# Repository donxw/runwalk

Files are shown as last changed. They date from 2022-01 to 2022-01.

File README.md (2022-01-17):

# runwalk timer
Timer to help in trainging for marathons.  Set run vs walk time.  Ratio of run to walk is set by web page hosted by the ESP32.

## parts ##

1.  Heltec WifiKit32 with built in OLED screen
2.  400 mAh lipo battery
3.  Switch
4.  Piezo Buzzer

## wiring ##
runwalk_wiring

## operation ##
Power on device.  No default is set so on first boot follow these steps:
* connect to wireless AP broadcast by the ESP32:  SSID: runwalk / Password: 12345678
* navigate to webpage 192.168.10.2
* fill in the desired run and walk cycle times
* runwalk_webpage
* click submit - on submit the ESP32 will store the settings in EEPROM for future default settings
* disconnect from the wireless AP

Screen will show how much time you have run or walked, total cumulative run/walk time, icon to show current walk or run cycle and a bar chart to show how much time is left in the current cycle.
fullview (Small)

Piezo speaker will create a low-high tone when it is time to switch to running, 
run (Small)

and a high-low tone when it is time to walk.
walk (Small)

## case ##
A 3D printed case and plastic lens encase the electonics, buzzer and battery for use when running:
InCase (Small)

A switch and charging / programming port are on one side.  Note that the switch needs to be in the on position when charging the battery.

Connector (Small)

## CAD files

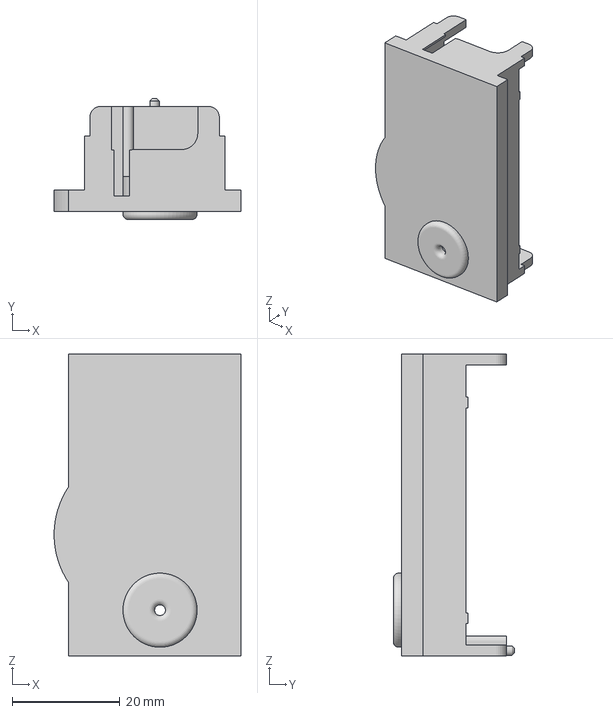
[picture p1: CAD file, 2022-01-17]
WalkRunTimer32v1/LowerCase^WalkRunAssembly.3mf
34.6 x 22.5 x 56.0 mm

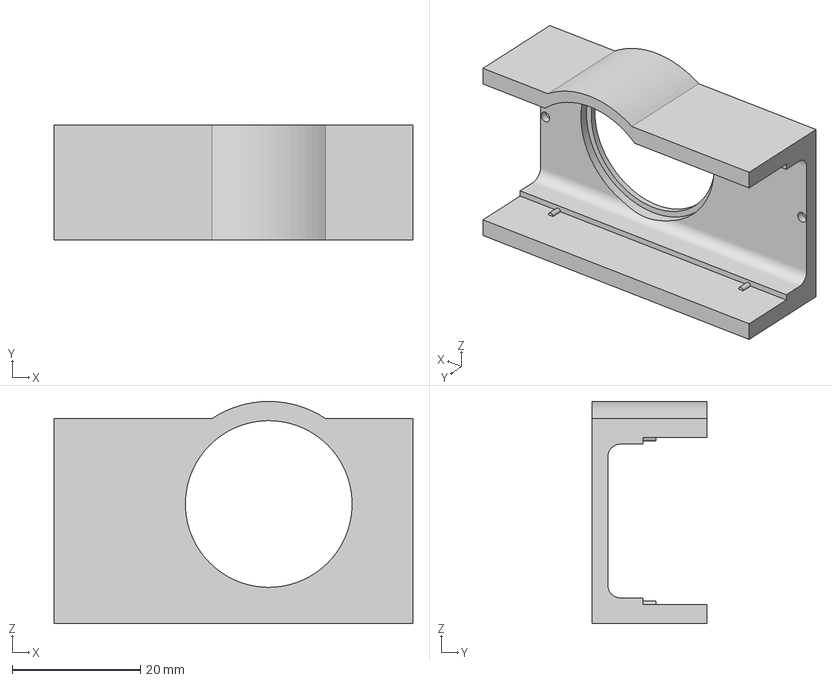
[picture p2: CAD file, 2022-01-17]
WalkRunTimer32v1/UpperCase.3mf
56.0 x 18.0 x 34.6 mm

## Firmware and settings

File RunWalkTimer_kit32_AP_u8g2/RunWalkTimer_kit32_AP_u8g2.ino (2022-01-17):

//Board:  Heltec Wifi Kit32
//https://www.w3schools.com/bootstrap/ to create index.h

#include <SPI.h>
#include <Wire.h>
#include <Adafruit_GFX.h>
#include <Adafruit_SSD1306.h>
#include <U8g2_for_Adafruit_GFX.h>
#include <Tone32.h>  //https://github.com/lbernstone/Tone
#include "UserSettings.h"

// WiFi and AP
#include <WiFi.h>
#include <WiFiClient.h>
#include <WebServer.h>
#include <DNSServer.h>
#include <EEPROM.h>
#include "index.h"

// Display Settings
#define SCREEN_WIDTH 128 // OLED display width, in pixels  128
#define SCREEN_HEIGHT 64 // OLED display height, in pixels  64
#define OLED_RESET     16 // For built in OLED wifikit8
Adafruit_SSD1306 display(SCREEN_WIDTH, SCREEN_HEIGHT, &Wire, OLED_RESET);
U8G2_FOR_ADAFRUIT_GFX u8display;

//  EEPROM configuration - 24 bytes
#define EEPROM_SIZE 24  /* new */

//  Settings for AP
const byte DNS_PORT = 53;
IPAddress apIP(192, 168, 10, 2); // hard code AP IP address (optional - default is 192.168.4.1)
DNSServer dnsServer;
WebServer server(80); //Server on port 80

// Intitialize variables
unsigned long previousTime = 0; // store the last time the led variable was updated
int led = 0;  //used as a counting variable and doubles as the number of LEDs to be lit
double cum_led = 0;  //cumulative count
bool walktime = true;
bool useEEPROMvalues = false;
bool useEEPROMnextboot = false;
bool toneOn = true;
int x_offset = 12;  //offset for led

// 600000 = 10 minutes in milliseconds (10 * 60 * 1000)
// 60000 = 1 minute in milliseconds
// 6000 = 6 sec in milliseconds
long interval = 10000; // 10sec interval - increments LED count
long setupInterval = 10000; // interval before moving out of setup automatically
int selectmode = 0;  // variable to store display function mode

//===============================================================
// This routine is executed when you open its IP in browser
//===============================================================
void handleRoot() {
  String s = MAIN_page; //Read HTML contents
  server.send(200, "text/html", s); //Send web page
}
//===============================================================
// This routine is executed when you press submit
//===============================================================
void handleForm() {
  String run__duration = server.arg("runTime");
  String walk__duration = server.arg("walkTime");
  String tone__on = server.arg("tone");

  // this is a cool way to convert string from the web page to an integer
  run_duration = atoi(run__duration.c_str());
  walk_duration = atoi(walk__duration.c_str());

  run_duration = run_duration * 1000 / interval;
  walk_duration = walk_duration * 1000 / interval;

  Serial.print("Run Duration:");
  Serial.println(run_duration);

  Serial.print("Walk Duration:");
  Serial.println(walk_duration);

  toneOn = (tone__on == "on") ? true : false;
  Serial.print("Tone is:  "); Serial.println(toneOn);

  selectmode = 1;  //set to one to start the run / walk cycle
  Serial.print("Selectmode = "); Serial.println(selectmode);

  led = 0; //set led count back to zero on new settings
  cum_led = 0;  //reset cumulative time back to zero

  useEEPROMnextboot = 1;  //flag to read from eeprom

  //Update web page with input values
  server.send(200, "text/html", run__duration + " " + walk__duration); //Send web page

  //Write values to EEPROM for next boot
  EEPROM.write(0, run_duration);
  EEPROM.write(1, walk_duration);
  EEPROM.write(2, useEEPROMnextboot);
  EEPROM.commit();


  // reset first display
  display.clearDisplay();
  u8display.setCursor(x_offset, 10);
  u8display.print("Walking: ");
  u8display.print(led * 10);
  u8display.println(" sec");
  display.drawBitmap(
    ((display.width() - 32 ) / 2) + 45,
    ((display.height() - 32) / 2) + 10,
    myWalker, 32, 32, 1);
  u8display.setCursor(x_offset, 25);
  u8display.print("Total: ");
  u8display.print(cum_led * interval / (60 * 1000));  u8display.println(" min");
  display.fillRect(0, 60, (10 * (walk_duration - led) * 127) / (10 * walk_duration), 4, WHITE);
  display.display();
}


void setup() {
  unsigned long currentTime = millis();

  // Set up EEPROM storage
  //===============================================================
  EEPROM.begin(EEPROM_SIZE);

  // initialize display
  Wire.begin(4, 15);
  // SSD1306_SWITCHCAPVCC = generate display voltage from 3.3V internally
  if (!display.begin(SSD1306_SWITCHCAPVCC, 0x3C)) { // Address 0x3C for 128x32
    Serial.println(F("SSD1306 allocation failed"));
    for (;;); // Don't proceed, loop forever
  }
  u8display.begin(display);  //connect u8g2 to adafruit gfx
  u8display.setFont(u8g2_font_ordinarybasis_tr); //u8g2_font_ordinarybasis_t_all
  //u8display.setFont(u8g2_font_seraphimb1_tr);
  //u8display.setFont(u8g2_font_koleeko_tf);
  //u8display.setFont(u8g2_font_DigitalDiscoThin_te);
  u8display.setFontMode(1);
  u8display.setFontDirection(0);
  u8display.setForegroundColor(WHITE);
  u8display.setCursor(0, 10);
  display.setRotation(0);  //0 is normal, 1 is 90, 2 is 180 and 3 is 270deg

  Serial.begin(115200);

  //Settings for webserver
  WiFi.mode(WIFI_AP); //Access Point mode
  WiFi.softAP("runwalk", "12345678");    //Password length minimum 8 char
  //WiFi.softAPConfig(local_ip, gateway, subnet);  //Optional - only if you don't want the default
  WiFi.softAPConfig(apIP, apIP, IPAddress(255, 255, 255, 0));
  dnsServer.setTTL(300); // modify TTL with the domain name from 60 to 300seconds
  dnsServer.setErrorReplyCode(DNSReplyCode::ServerFailure);
  dnsServer.start(DNS_PORT, "www.walkrun.com", apIP);  // set website name

  //Map server actions to functions
  server.on("/", handleRoot);      //Which routine to handle at root location
  server.on("/action_page", handleForm); //form action is handled here
  server.begin();                  //Start server
  Serial.println("HTTP server started");
  display.clearDisplay();
  u8display.setCursor(x_offset, 30);
  u8display.println("Connect Wifi to");
  u8display.setCursor(x_offset, 45);
  u8display.print("runwalk");
  display.display();
  display.setCursor(0, 10);

  delay(3000);  // delay to allow connection

  display.clearDisplay();
  u8display.setCursor(x_offset, 30);
  u8display.print("go to: ");
  u8display.print("192.168.10.2");
  display.display();

delay(1000);  //delay to read

  // convert walk_duration to number of loop cycles based on interval
  walk_duration = walk_duration * 1000 / interval; // convert to ms then divide by interval which is also in ms
  run_duration = run_duration * 1000 / interval;
  Serial.print("walk_duration:  ");  Serial.println(walk_duration);

  //Read values from eeprom if flag is set
  useEEPROMnextboot = EEPROM.read(2);
  // test to see if values were stored in EEPROM and load them
  Serial.print("useEEPROMnextboot from EEPROM: "); Serial.println(useEEPROMnextboot);
  if (useEEPROMnextboot = 1) {
    run_duration = EEPROM.read(0);
    walk_duration = EEPROM.read(1);
    Serial.println("*****From EEPROM**********");
    Serial.print("walk_duration: "); Serial.println(walk_duration);
    Serial.print("run_duration: "); Serial.println(run_duration);
  }

  Serial.println("Setup Complete");
  Serial.print("Selectmode = "); Serial.println(selectmode);

}

void loop() {

  // store the time since the Arduino started running in a variable
  unsigned long currentTime = millis();

  switch (selectmode) {

    case 0:  // walking

      server.handleClient();          //Handle client requests


      if (currentTime - previousTime > setupInterval) {
        previousTime = currentTime;

        // change selectmode to start run/walk cycle
        selectmode = 1;
        Serial.print("Selectmode: "); Serial.println(selectmode);

        led = 0;
        // first display
        display.clearDisplay();
        u8display.setCursor(x_offset, 10);
        u8display.print("Walking: ");
        u8display.print(led * 10);
        u8display.println(" sec");
        display.drawBitmap(
          ((display.width() - 32 ) / 2) + 45,
          ((display.height() - 32) / 2) + 10,
          myWalker, 32, 32, 1);
        u8display.setCursor(x_offset, 25);
        u8display.print("Total: ");
        u8display.print(cum_led * interval / (60 * 1000));  u8display.println(" min");
        display.fillRect(0, 60, (10 * (walk_duration - led) * 127) / (10 * walk_duration), 4, WHITE);
        display.display();
      }
      break;

    case 1:  //running

      server.handleClient();          //Handle client requests

      // begin walk / run alternate timing
      if (walktime == false) {
        if (currentTime - previousTime > interval) {
          previousTime = currentTime;
          // increment the led variable
          led++;
          cum_led++;

          // update Display
          display.clearDisplay();
          u8display.setCursor(x_offset, 10);
          u8display.print("Running: ");
          u8display.print(led * 10);
          u8display.println(" sec");
          display.drawBitmap(
            ((display.width() - 32 ) / 2) + 45,
            ((display.height() - 32) / 2) + 10,
            myRunner, 32, 32, 1);
          u8display.setCursor(x_offset, 25);
          u8display.print("Total: ");
          u8display.print(cum_led * interval / (60 * 1000));  u8display.println(" min");
          display.fillRect(0, 60, (10 * (run_duration - led) * 127) / (10 * run_duration), 4, WHITE); // display.fillrect(xi,yi,width,height,color)
          display.display();
          if (led == 2) {
            u8display.setCursor(x_offset, 45);
            u8display.println("Doing great!");
            display.display();
          }
          if (led == 4) {
            u8display.setCursor(x_offset, 45);
            u8display.println("Awesome!");
            display.display();
          }


          // check if run duration is complete
          if (led >= run_duration) {  //if interval is set to 10 sec, then this loop triggers at the end of 60 seconds
            // time is up
            led = 0;
            display.clearDisplay();
            u8display.setCursor(x_offset, 10);
            //u8display.print("Running: ");
            u8display.print("Walking: ");
            u8display.print(led * 10);
            u8display.println(" sec");
            display.drawBitmap(
              ((display.width() - 32 ) / 2) + 45,
              ((display.height() - 32) / 2) + 10,
              myWalker, 32, 32, 1);
            display.display();
            u8display.setCursor(x_offset, 25);
            u8display.print("Total: ");
            u8display.print(cum_led * interval / (60 * 1000));  u8display.println(" min");
            u8display.setCursor(x_offset, 45);
            u8display.println("Time to Walk!");
            display.fillRect(0, 60, (10 * (run_duration - (led)) * 127) / (10 * run_duration), 4, WHITE);
            display.display();
            //led = 0;
            walktime = true;
            if (toneOn == true) {
              playdowntone();
            }
          }
        }
      }

      // repeat countup for Walking

      if (walktime == true) {
        if (currentTime - previousTime > interval) {
          previousTime = currentTime;
          // increment led variable
          led++;
          cum_led++;

          // update display
          display.clearDisplay();
          u8display.setCursor(x_offset, 10);
          u8display.print("Walking:  ");
          u8display.print(led * 10);
          u8display.println(" sec");
          display.drawBitmap(
            ((display.width() - 32 ) / 2) + 45,
            ((display.height() - 32) / 2) + 10,
            myWalker, 32, 32, 1);
          u8display.setCursor(x_offset, 25);
          u8display.print("Total: ");
          u8display.print(cum_led * interval / (60 * 1000));  u8display.println(" min");
          display.fillRect(0, 60, (10 * (walk_duration - led) * 127) / (10 * walk_duration), 4, WHITE);
          display.display();

          // check to see if walk duration is complete
          if (led >= walk_duration) {
            // time is up
            led = 0;
            display.clearDisplay();
            u8display.setCursor(x_offset, 10);
            //u8display.print("Walking: ");
            u8display.print("Running: ");
            u8display.print(led * 10);
            u8display.println(" sec");
            display.drawBitmap(
              ((display.width() - 32 ) / 2) + 45,
              ((display.height() - 32) / 2) + 10,
              myRunner, 32, 32, 1);
            display.display();
            u8display.setCursor(x_offset, 25);
            u8display.print("Total: ");
            u8display.print(cum_led * interval / (60 * 1000));  u8display.println(" min");
            u8display.setCursor(x_offset, 45);
            u8display.println("Time to Run!");
            display.fillRect(0, 60, (10 * (walk_duration - (led)) * 127) / (10 * walk_duration), 4, WHITE);
            display.display();
            //led = 0;
            walktime = false;
            if (toneOn == true) {
              playuptone();
            }
          }
        }
      }
  }
}

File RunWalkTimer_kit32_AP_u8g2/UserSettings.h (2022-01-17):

#define audiopin 26  //gpio26
#define audiochannel 0

int walk_duration = 120; // set walk duration in seconds
int run_duration = 60; // set run duration in seconds


// ************* Image Bitmaps **********************************
// Images used in program were generated at http://javl.github.io/image2cpp/
const unsigned char myRunner [] PROGMEM = {
  // 'runner, 32x32px
  0x00, 0x00, 0x00, 0x00, 0x00, 0x00, 0x07, 0x80, 0x00, 0x00, 0x0f, 0xc0, 0x00, 0x00, 0x1f, 0xc0, 
  0x00, 0x00, 0x1f, 0xe0, 0x00, 0x00, 0x1f, 0xe0, 0x00, 0x00, 0x1f, 0xc0, 0x00, 0x00, 0x4f, 0x80, 
  0x00, 0x03, 0xf2, 0x00, 0x00, 0x3f, 0xfc, 0x00, 0x00, 0xff, 0xff, 0x3c, 0x01, 0xff, 0xff, 0xfc, 
  0x00, 0xe1, 0xff, 0xfc, 0x00, 0x03, 0xff, 0xf0, 0x00, 0x03, 0xf8, 0x00, 0x00, 0x07, 0xf8, 0x00, 
  0x00, 0x0f, 0xf0, 0x00, 0x00, 0x0f, 0xf8, 0x00, 0x00, 0x1f, 0xfc, 0x00, 0x00, 0x1e, 0xfe, 0x00, 
  0x00, 0x7e, 0x3e, 0x00, 0x07, 0xfc, 0x3e, 0x00, 0x3f, 0xfc, 0x3c, 0x00, 0x3f, 0xf8, 0x7c, 0x00, 
  0x3f, 0x80, 0x78, 0x00, 0x3c, 0x00, 0xf8, 0x00, 0x00, 0x01, 0xf0, 0x00, 0x00, 0x01, 0xf0, 0x00, 
  0x00, 0x03, 0xe0, 0x00, 0x00, 0x03, 0xc0, 0x00, 0x00, 0x01, 0xc0, 0x00, 0x00, 0x00, 0x00, 0x00
};
const unsigned char myWalker [] PROGMEM = {
  // 'walker, 32x32px
  0x00, 0x00, 0x00, 0x00, 0x00, 0x00, 0x70, 0x00, 0x00, 0x00, 0xf8, 0x00, 0x00, 0x00, 0xfc, 0x00, 
  0x00, 0x00, 0xfc, 0x00, 0x00, 0x00, 0xf8, 0x00, 0x00, 0x00, 0x70, 0x00, 0x00, 0x00, 0x80, 0x00, 
  0x00, 0x07, 0xe0, 0x00, 0x00, 0x3f, 0xe0, 0x00, 0x00, 0xff, 0xf0, 0x00, 0x00, 0xff, 0xf8, 0x00, 
  0x00, 0xe7, 0xf8, 0x00, 0x00, 0xef, 0xfe, 0x00, 0x01, 0xcf, 0xdf, 0x80, 0x01, 0xcf, 0xcf, 0xc0, 
  0x01, 0xcf, 0x83, 0xc0, 0x00, 0xcf, 0x80, 0x00, 0x00, 0x0f, 0x80, 0x00, 0x00, 0x0f, 0xc0, 0x00, 
  0x00, 0x1f, 0xc0, 0x00, 0x00, 0x1f, 0xe0, 0x00, 0x00, 0x3f, 0xe0, 0x00, 0x00, 0x3d, 0xf0, 0x00, 
  0x00, 0x7c, 0xf0, 0x00, 0x00, 0x78, 0xf8, 0x00, 0x00, 0x78, 0x78, 0x00, 0x00, 0xf0, 0x7c, 0x00, 
  0x00, 0xf0, 0x3c, 0x00, 0x00, 0xe0, 0x1c, 0x00, 0x00, 0x00, 0x18, 0x00, 0x00, 0x00, 0x00, 0x00
};

#include "Pitches.h"

// notes in the melody:
int melody[] = {
  NOTE_C4, NOTE_G3, NOTE_G3, NOTE_A3, NOTE_G3, 0, NOTE_B3, NOTE_C4
};

int melody_down[] = {
  NOTE_F6, NOTE_D6
};

int melody_up[] = {
  NOTE_D6, NOTE_F6
};

// note durations: 4 = quarter note, 8 = eighth note, etc.:
int noteDurations[] = {
  4, 8, 8, 4, 4, 4, 4, 4
};

int noteDurationsDown[] = {
  8, 4
};


void playdowntone() {
  // iterate over the notes of the melody:
  for (int thisNote = 0; thisNote < 2; thisNote++) {

    // to calculate the note duration, take one second divided by the note type.
    //e.g. quarter note = 1000 / 4, eighth note = 1000/8, etc.
    int noteDuration = 1000 / noteDurationsDown[thisNote];
    tone(audiopin, melody_down[thisNote], noteDuration, audiochannel);

    // to distinguish the notes, set a minimum time between them.
    // the note's duration + 30% seems to work well:
    int pauseBetweenNotes = noteDuration * 1.20;
    delay(pauseBetweenNotes);
    // stop the tone playing:
    noTone(audiopin, audiochannel);
  }
}

void playuptone() {
  // iterate over the notes of the melody:
  for (int thisNote = 0; thisNote < 2; thisNote++) {

    // to calculate the note duration, take one second divided by the note type.
    //e.g. quarter note = 1000 / 4, eighth note = 1000/8, etc.
    int noteDuration = 1000 / noteDurationsDown[thisNote];
    tone(audiopin, melody_up[thisNote], noteDuration, audiochannel);

    // to distinguish the notes, set a minimum time between them.
    // the note's duration + 30% seems to work well:
    int pauseBetweenNotes = noteDuration * 1.30;
    delay(pauseBetweenNotes);
    // stop the tone playing:
    noTone(audiopin, audiochannel);
  }
}

void playtone() {
  // iterate over the notes of the melody:
  for (int thisNote = 0; thisNote < 8; thisNote++) {

    // to calculate the note duration, take one second divided by the note type.
    //e.g. quarter note = 1000 / 4, eighth note = 1000/8, etc.
    int noteDuration = 1000 / noteDurations[thisNote];
    tone(audiopin, melody[thisNote], noteDuration, audiochannel);

    // to distinguish the notes, set a minimum time between them.
    // the note's duration + 30% seems to work well:
    int pauseBetweenNotes = noteDuration * 1.30;
    delay(pauseBetweenNotes);
    // stop the tone playing:
    noTone(audiopin, audiochannel);
  }
}
